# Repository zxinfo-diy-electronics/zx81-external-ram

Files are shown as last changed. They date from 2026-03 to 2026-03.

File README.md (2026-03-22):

# zx81-external-ram module 16K/32K
Simple and compact external RAM interface for the ZX81 with WRX compability. First version is a 16K module and can be used on ZX80 and Lambda 8300 or simlar as well. The interface is made using THT components, making it easy for everyone to make.

The interface has been tested with the following 32K SRAM chips, all running Beamrider perfectly.
- UM62256E-70LL
- HM62256BLP-10
- AS6C62256-55PCN

| <!---> | <!---> |
| --- | --- |
|||

## version 1.2 - minor modification
It turns out that v1.1 does not work together with the zx81-external-eprom interface, due to issues with the ROMCS line that can be fixed with a diode on the ROMCS line. The schema has been updated with this fix, but if you already have a v1.1 PCB it's easy to do the fix.

- Cut the ROMCS trace on the back - and put in a diode, eg. 1N4148 instead - as shown here:



And now it runs fine with the zx81-external-eprom interface as well.



BOM for v1.2 (ROMCS fix)
- same as v1.1
- Diode 1N4144 (or similar)

## version 1.1 - full 32K support, with data in the 32-48K area.
Most version for internal 32K RAM puts the extra 16K at the top, 48 to 64K - but this is not what most 32K program expects. The 32K programs I have found expect the 32K from 16K, which requires some extra logic - another issue with this configuration is that normaly the ROM is mirrored between 32 and 48K, which means the ROM has to be disabled when the ZX81 access this part of the memory. I also decided to change the diodes from 1N4148 to BAT85 as suggested in general for this type of usage.

A little prototyping based on the v1.0 board - and yes, 32K from adress 16384 is all good here tested with Beamrider that require 32K and WRX :-)
| <!---> | <!---> |
| --- | --- |
|||

### Test using SYSINFO.P v0.02
This test program examines the memory configuration and reports this, 32K ram starting from address 0x4000 :-)



### Programs tested with success so far:
- [Beamrider](https://problemkaputt.de/beamride.htm), 32K and WRX graphics 
- [MaxDemo](https://demozoo.org/productions/159644/), 32K and WRX graphics (impressive 320x240 resolution)
- [Cross Snake](https://github.com/Fabrizio-Caruso/CROSS-LIB/releases/tag/XSnake2.0), 32K and WRX
- [Cross Chase](https://github.com/Fabrizio-Caruso/CROSS-LIB/releases/tag/WRX), 32K and WRX
- [Space Invaders](https://splintergu.itch.io/space-invaders-for-zx81-wrx), 32K and WRX

32K Programs NOT working - as they require internal modification in order to run M/C above 32K area.
- [The Crystal Frog](https://www.sinclairzxworld.com/viewtopic.php?t=334)

BOM for v1.1 (32K, continously from adress 16384)
- LED 3mm
- Resistor 470 Ohm
- Resistor 4K7 Ohm
- Resistor 10K Ohm
- 2 x Ceramic capacitor 100nF, P2,54
- 1 x Ceramic capacitor 1,2nF, P2,54
- 2 x Diode BAT85
- 74LS00
- 74LS32
- RAM 62256 or similar
- ZX81 Edge Connector or my [ZX81 Bus Extender](https://github.com/thomasheckmann/zx81-bus-extender)

## version 1.0 - 16K with WRX support
The interface for now is only using 16K from the 62256 memory chip, using the other half 16K might be added on later version. I might also consider making a SMD version, making it even smaller in size :-)

| SCHEMA | PCB |
| --- | --- |
|||

The PCB arrived, so I populated it with some components (all written on the silkscreen).



BOM for v1.0 (16K only)
- LED 3mm
- Resistor 470 Ohm
- Resistor 4K7 Ohm
- 2 x Ceramic capacitor 100nF, P2,54
- 2 x Diode 1N4148
- 74LS00
- RAM 62256 or similar
- ZX81 Edge Connector or my [ZX81 Bus Extender](https://github.com/thomasheckmann/zx81-bus-extender)
  
NOTE: WRX hi-res, to get full support for hi-res WRX a cercamic capacitor is needed between PIN 20 (CS) and GND. In this build with a KM62256ALP-10 a 1,2nF ceramic capacitor should be fitted. 

The value for the capacitor for different 62256 SRAM chips tested with [STARFIGHT](https://problemkaputt.de/starfigh.htm)

- KM62256ALP-10, 1.2nF

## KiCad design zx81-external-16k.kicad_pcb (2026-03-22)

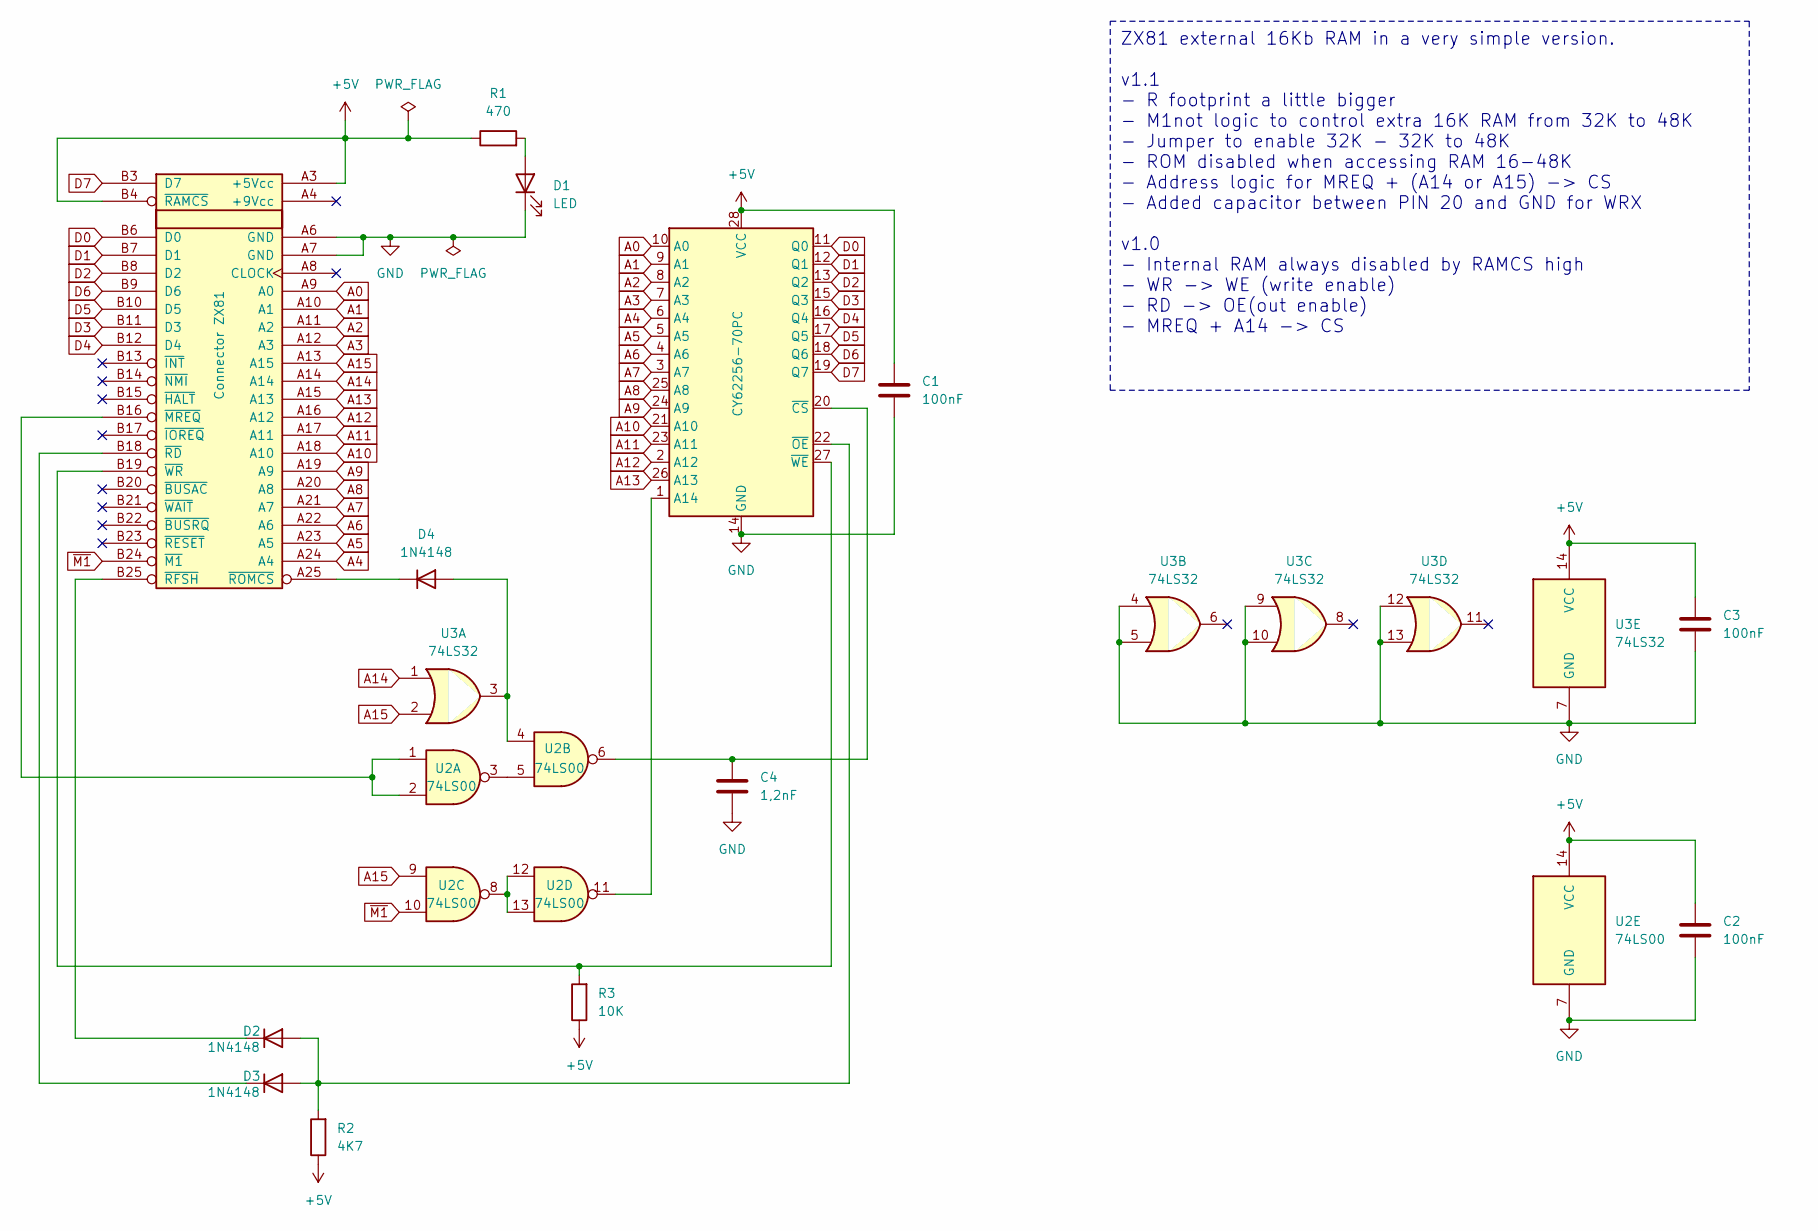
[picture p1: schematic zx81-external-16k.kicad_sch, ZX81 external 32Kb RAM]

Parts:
C1, C2, C3: 100nF; C_Disc_D3.0mm_W1.6mm_P2.50mm
C4: 1,2nF; C_Disc_D3.0mm_W1.6mm_P2.50mm
D1: LED; LED_D3.0mm
D2, D3, D4: 1N4148; D_DO-35_SOD27_P7.62mm_Horizontal
J1: Connector ZX81; EDGE ZX81 BOTTOM
R1: 470; R_Axial_DIN0207_L6.3mm_D2.5mm_P10.16mm_Horizontal
R2: 4K7; R_Axial_DIN0207_L6.3mm_D2.5mm_P10.16mm_Horizontal
R3: 10K; R_Axial_DIN0207_L6.3mm_D2.5mm_P10.16mm_Horizontal
U1: CY62256-70PC; DIP-28_W15.24mm
U2: 74LS00; DIP-14_W7.62mm
U3: 74LS32; DIP-14_W7.62mm

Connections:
+5V: C1.1, C2.1, C3.1, J1.A3 (+5Vcc), J1.B4 (~RAMCS), R1.1, R2.1, R3.1, U1.28 (VCC), U2.14 (VCC), U3.14 (VCC)
A0: J1.A9 (A0), U1.10 (A0)
A1: J1.A10 (A1), U1.9 (A1)
A2: J1.A11 (A2), U1.8 (A2)
A3: J1.A12 (A3), U1.7 (A3)
A4: J1.A24 (A4), U1.6 (A4)
A5: J1.A23 (A5), U1.5 (A5)
A6: J1.A22 (A6), U1.4 (A6)
A7: J1.A21 (A7), U1.3 (A7)
A8: J1.A20 (A8), U1.25 (A8)
A9: J1.A19 (A9), U1.24 (A9)
A10: J1.A18 (A10), U1.21 (A10)
A11: J1.A17 (A11), U1.23 (A11)
A12: J1.A16 (A12), U1.2 (A12)
A13: J1.A15 (A13), U1.26 (A13)
A14: J1.A14, U3.1
A15: J1.A13 (A15), U2.9, U3.2
D0: J1.B6 (D0), U1.11 (Q0)
D1: J1.B7 (D1), U1.12 (Q1)
D2: J1.B8 (D2), U1.13 (Q2)
D3: J1.B11 (D3), U1.15 (Q3)
D4: J1.B12 (D4), U1.16 (Q4)
D5: J1.B10 (D5), U1.17 (Q5)
D6: J1.B9 (D6), U1.18 (Q6)
D7: J1.B3 (D7), U1.19 (Q7)
GND: C1.2, C2.2, C3.2, C4.2, D1.1 (K), J1.A6 (GND), J1.A7 (GND), U1.14 (GND), U2.7 (GND), U3.4, U3.5, U3.7 (GND), U3.9, U3.10, U3.12, U3.13
unnamed: D1.2 (A), R1.2
unnamed: D2.2 (A), D3.2 (A), R2.2, U1.22 (~OE)
unnamed: D2.1 (K), J1.B25 (~RFSH)
unnamed: D3.1 (K), J1.B18 (~RD)
unnamed: D4.2 (A), U2.4, U3.3
unnamed: D4.1 (K), J1.A25 (~ROMCS)
unnamed: J1.B16 (~MREQ), U2.1, U2.2
unnamed: J1.B19 (~WR), R3.2, U1.27 (~WE)
unnamed: U1.1 (A14), U2.11
unnamed: C4.1, U1.20 (~CS), U2.6
unnamed: U2.3, U2.5
unnamed: U2.8, U2.12, U2.13
~M1: J1.B24 (~M1), U2.10

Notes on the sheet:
ZX81 external 16Kb RAM in a very simple version. v1.1 - R footprint a little bigger - M1not logic to control extra 16K RAM from 32K to 48K - Jumper to enable 32K - 32K to 48K - ROM disabled when accessing RAM 16-48K - Address logic for MREQ + (A14 or A15) -> CS - Added capacitor between PIN 20 and 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

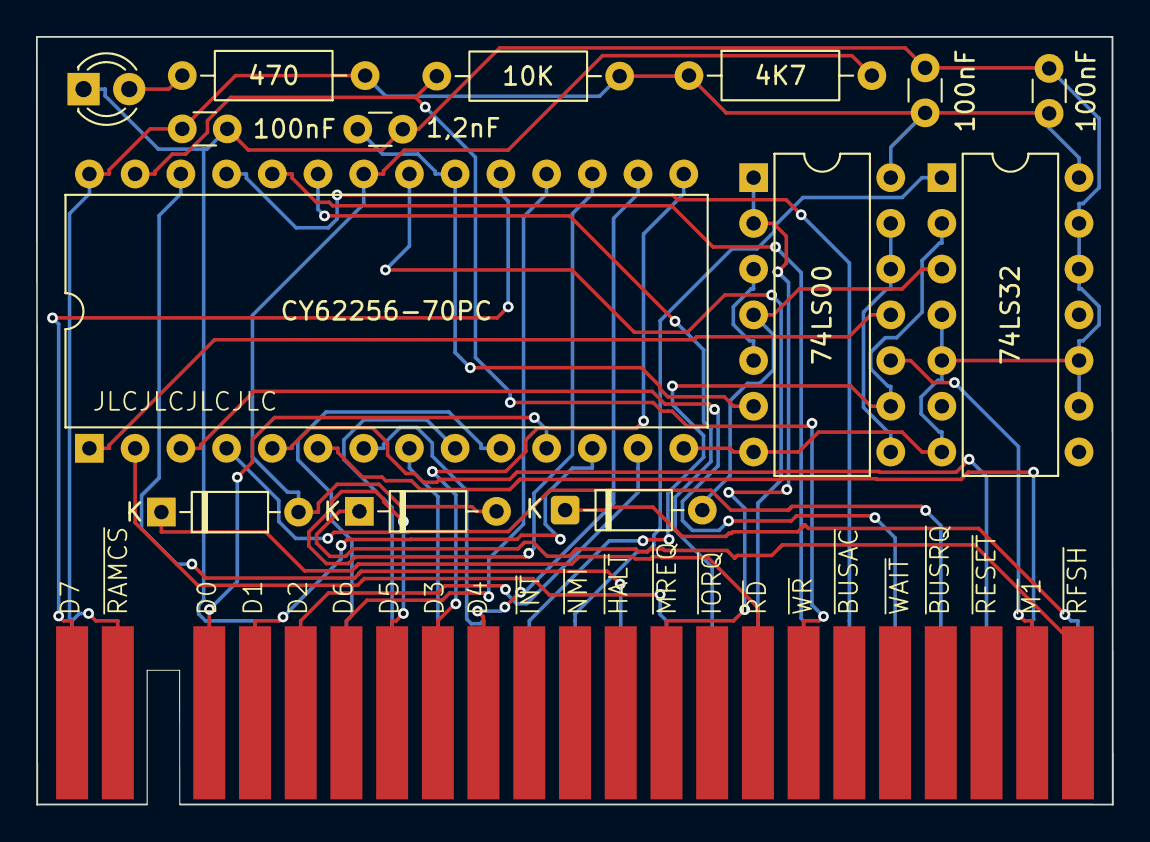
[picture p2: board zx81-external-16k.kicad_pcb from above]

Board: 2 copper layers, 59.8 x 42.7 mm, 15 parts (0 on the bottom side), 39 nets.

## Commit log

2026-03-22 KiCad update
    [zx81-external-16k.kicad_pcb, zx81-external-16k.kicad_sch]
2026-03-22 Update README with BOM for v1.2 and version details
    Added BOM for v1.2 and updated version 1.1 details.
